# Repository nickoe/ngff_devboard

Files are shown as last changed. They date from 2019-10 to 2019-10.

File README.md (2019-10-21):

View this project on [CADLAB.io](https://cadlab.io/project/2228). 

This is a project to make "something" to put in the WWAN slot of my
laptop. This means M.2 NGFF with key B. Lets try to use USB as a
minimum. Maybe som STM32 chip as a start. Maybe it can be connected to
other things. This in turn means a maximum component area of 30mm x
42mm. Meaning TYPE 3042-xx-B. But I gues we could also go with TYPE
2242-xx-B-M, but this is smaller, but should fit a normal WWAN socket
location as well.

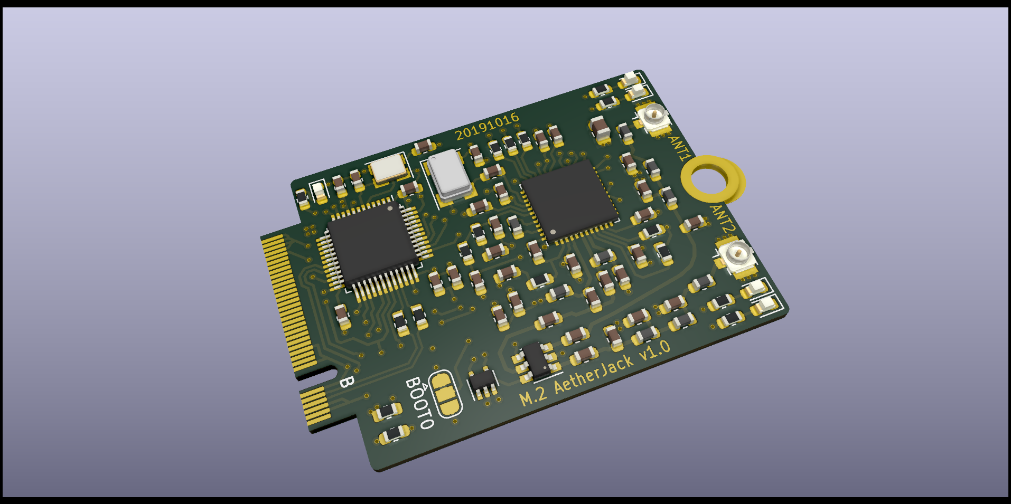
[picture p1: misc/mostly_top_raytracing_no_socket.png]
AetherJack


Or A + E?  Can we do A + B + E?

Even though there are USB in all of above the USB data lines are NOT
in the same pin location :( ... meaning that we go with the B key for
now as this seems to be the most common keying for WWAN modules for
laptops.

Mechanical constraints:
 - Type 3042-S3-B interface
   - 30x42mm
   - Component maximum height on top layer is 1.5mm
   - B keying
   - Board thickness is 0.8 mm.
   - No components on bottom side

   --- or should it be 2242-S3-B? 22mm instead of 30mm wide?
   - Refer to Table 30 for pinout
      Socket 2 Key B SSIC-based WWAN Adapter Pinouts

SIM card connections could be used for SWD programming
Make PCB ready for both STM32F407 and STM32F103

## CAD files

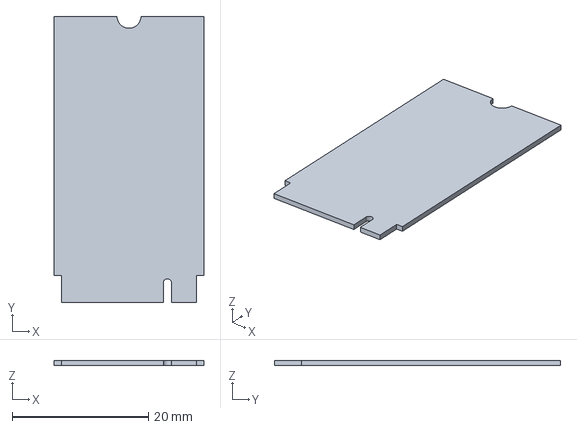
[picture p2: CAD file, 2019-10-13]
M.2 Type 2242-XX-B/M.2 Type 2242-XX-B.step
22.0 x 42.0 x 0.8 mm

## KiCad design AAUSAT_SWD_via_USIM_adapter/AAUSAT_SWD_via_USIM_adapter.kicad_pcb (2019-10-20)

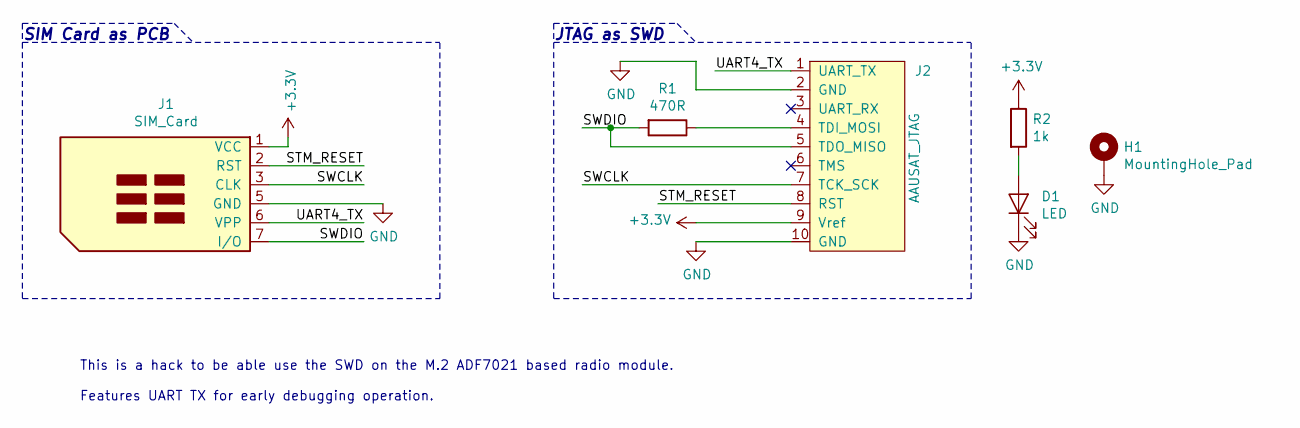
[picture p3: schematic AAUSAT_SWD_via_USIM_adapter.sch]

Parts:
D1: LED; LED_0603_1608Metric
H1: MountingHole_Pad; MountingHole_3.2mm_M3_Pad
J1: SIM_Card; UICC_2FF_mini_SIM_6_pads
J2: AAUSAT_JTAG; S10B-ZR-SM4A-TF(LF)(SN); digikey# 455-1700-1-ND;455-1197-ND;10:455-1130-1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
R1: 470R; R_0603_1608Metric
R2: 1k; R_0603_1608Metric

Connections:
+3V3: J1.1 (VCC), J2.9 (Vref), R2.1
/STM_RESET: J1.2 (RST), J2.8 (RST)
/SWCLK: J1.3 (CLK), J2.7 (TCK_SCK)
/SWDIO: J1.7 (I/O), J2.5 (TDO_MISO), R1.2
/UART4_TX: J1.6 (VPP), J2.1 (UART_TX)
GND: D1.1 (K), H1.1, J1.5 (GND), J2.2 (GND), J2.10 (GND)
unnamed: D1.2 (A), R2.2
unnamed: J2.4 (TDI_MOSI), R1.1

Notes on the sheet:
JTAG as SWD
SIM Card as PCB
This is a hack to be able use the SWD on the M.2 ADF7021 based radio module. Features UART TX for early debugging operation.

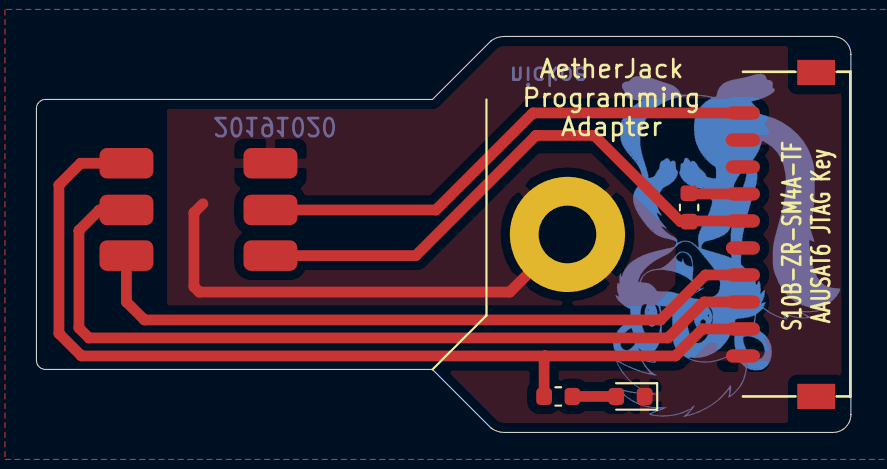
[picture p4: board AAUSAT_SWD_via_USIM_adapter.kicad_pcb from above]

Board: 2 copper layers, 45.2 x 22.0 mm, 6 parts (0 on the bottom side), 8 nets.

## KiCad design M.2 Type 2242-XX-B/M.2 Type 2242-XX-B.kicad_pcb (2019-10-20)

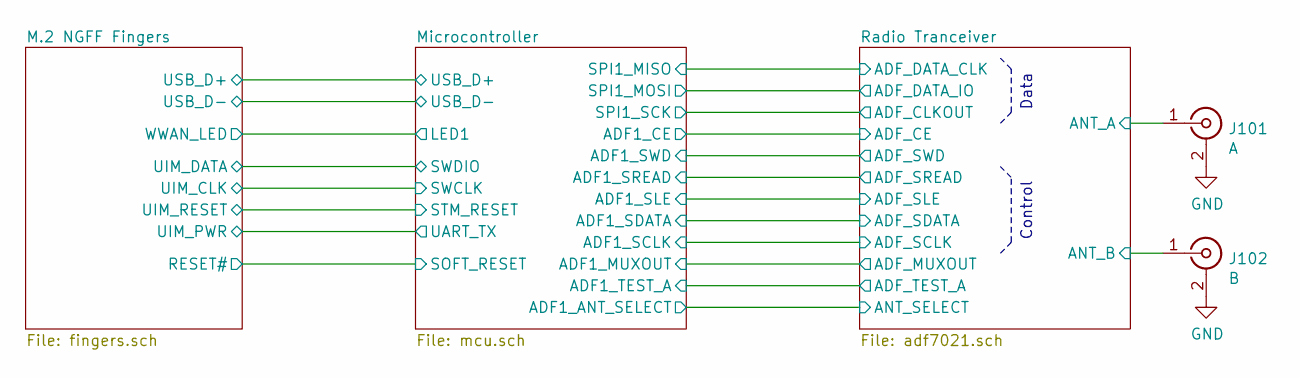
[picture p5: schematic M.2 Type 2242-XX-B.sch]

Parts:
J101: A; U.FL_Hirose_U.FL-R-SMT-1_Vertical
J102: B; U.FL_Hirose_U.FL-R-SMT-1_Vertical

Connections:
/Radio Tranceiver/ANT_A: J101.1 (In); also elsewhere on the board
/Radio Tranceiver/ANT_B: J102.1 (In); also elsewhere on the board
GND: J101.2 (Ext), J102.2 (Ext); also elsewhere on the board

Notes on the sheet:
Control
Data

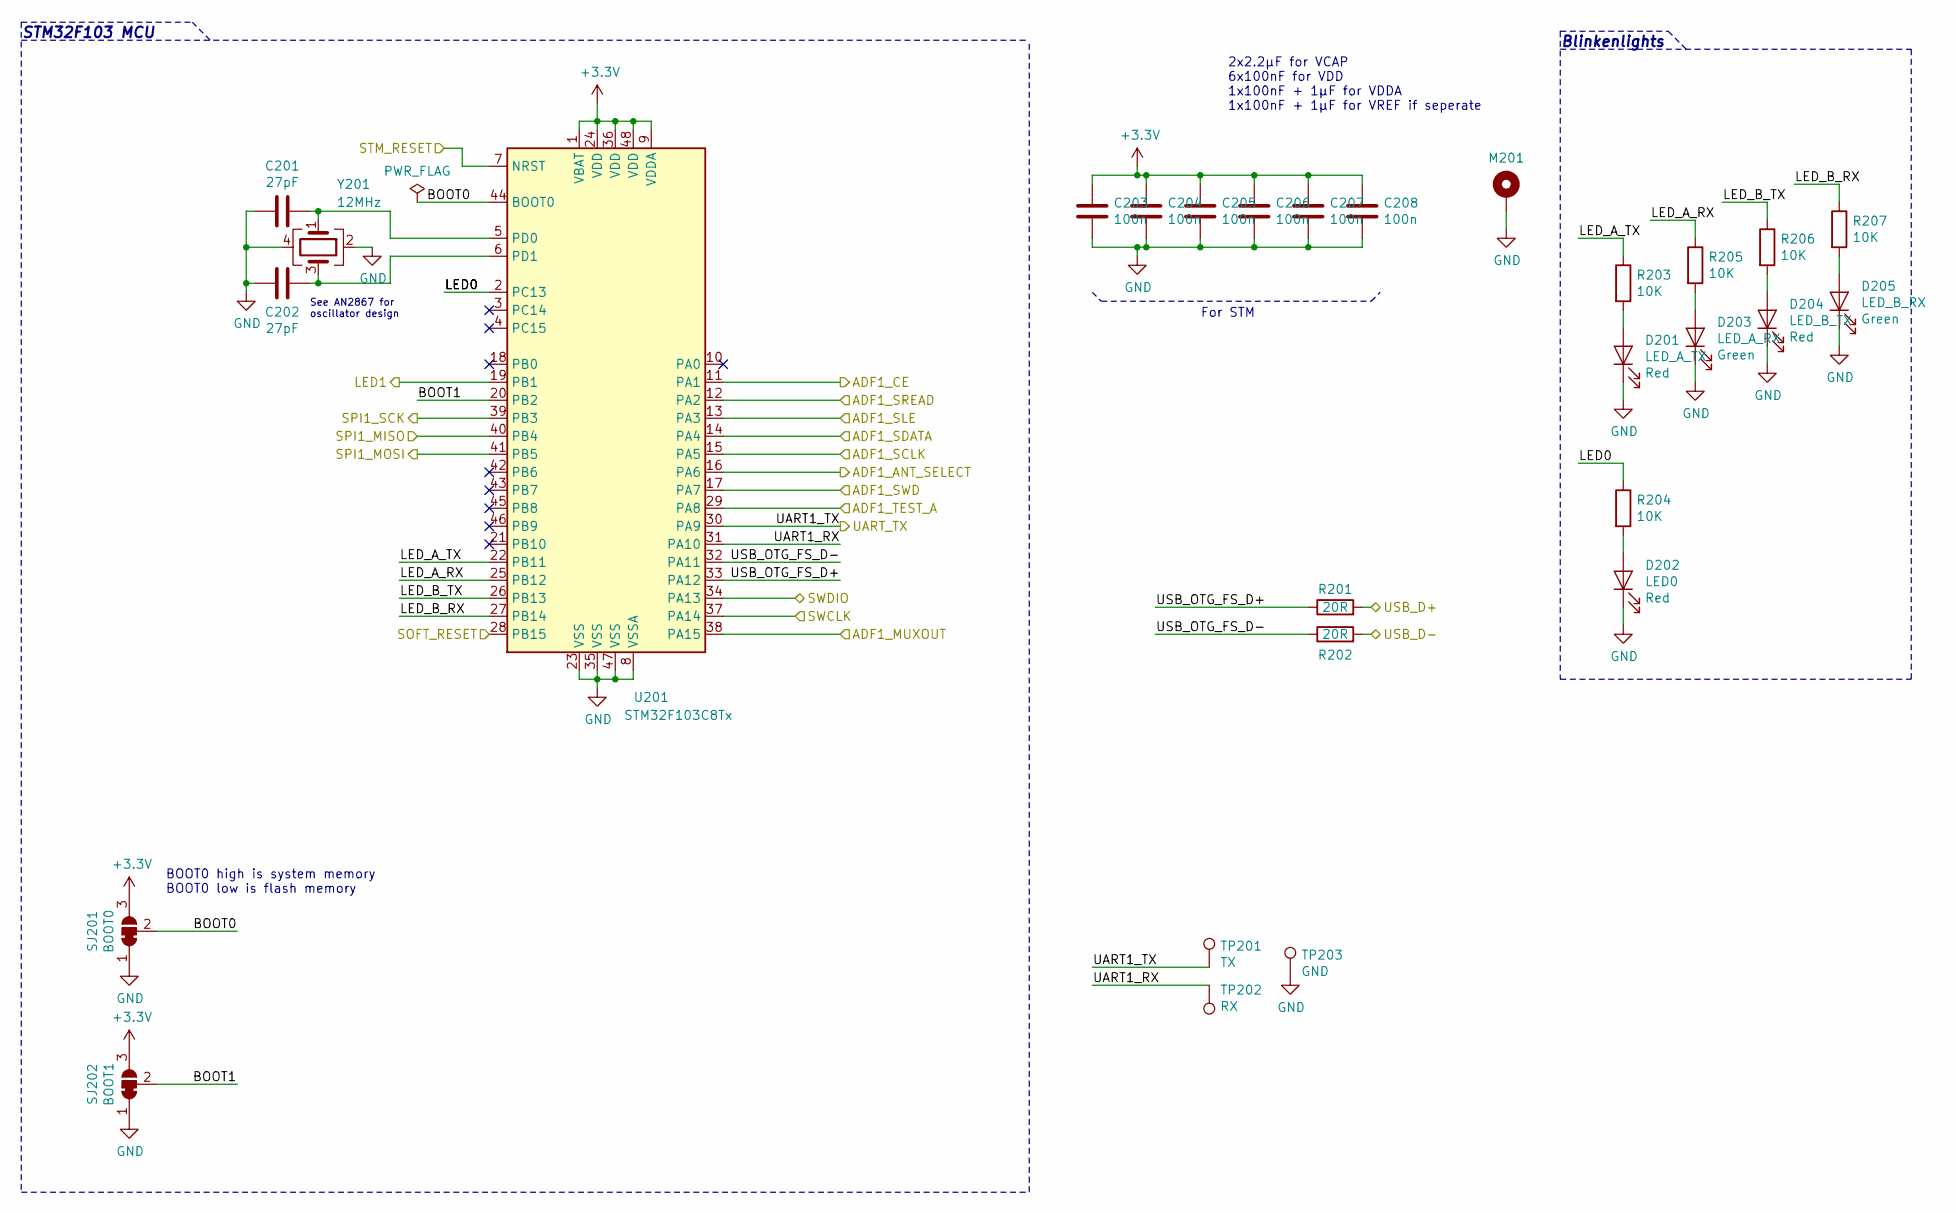
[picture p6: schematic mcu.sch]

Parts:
C201, C202: 27pF; C_0603_1608Metric
C203, C204, C205, C206, C207, C208: 100n; C_0603_1608Metric
D201: LED_A_TX; LED_0603_1608Metric
D202: LED0; LED_0603_1608Metric
D203: LED_A_RX; LED_0603_1608Metric
D204: LED_B_TX; LED_0603_1608Metric
D205: LED_B_RX; LED_0603_1608Metric
M201: MountingHole_Pad; M.2_Standoff_Card_Pad
R201, R202: 20R; R_0603_1608Metric
R203, R204, R205, R206, R207: 10K; R_0603_1608Metric
SJ201: BOOT0; SolderJumper-3_P1.3mm_Bridged12_RoundedPad1.0x1.5mm
SJ202: BOOT1; SolderJumper-3_P1.3mm_Bridged12_RoundedPad1.0x1.5mm
TP201: TX; TestPad
TP202: RX; TestPad
TP203: GND; TestPad
U201: STM32F103C8Tx; LQFP-48_7x7mm_P0.5mm
Y201: 12MHz; Crystal_SMD_3225-4Pin_3.2x2.5mm; digikey# 1923-1568-1-ND

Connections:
+3V3: C203.1, C204.1, C205.1, C206.1, C207.1, C208.1, SJ201.3 (B), SJ202.3 (B), U201.1 (VBAT), U201.9 (VDDA), U201.24 (VDD), U201.36 (VDD), U201.48 (VDD); also elsewhere on the board
/M.2 NGFF Fingers/RESET#: U201.28 (PB15); also elsewhere on the board
/M.2 NGFF Fingers/USB_D+: R201.2; also elsewhere on the board
/M.2 NGFF Fingers/USB_D-: R202.2; also elsewhere on the board
/Microcontroller/ADF1_ANT_SELECT: U201.16 (PA6); also elsewhere on the board
/Microcontroller/ADF1_CE: U201.11 (PA1); also elsewhere on the board
/Microcontroller/ADF1_MUXOUT: U201.38 (PA15); also elsewhere on the board
/Microcontroller/ADF1_SCLK: U201.15 (PA5); also elsewhere on the board
/Microcontroller/ADF1_SDATA: U201.14 (PA4); also elsewhere on the board
/Microcontroller/ADF1_SLE: U201.13 (PA3); also elsewhere on the board
/Microcontroller/ADF1_SREAD: U201.12 (PA2); also elsewhere on the board
/Microcontroller/ADF1_SWD: U201.17 (PA7); also elsewhere on the board
/Microcontroller/ADF1_TEST_A: U201.29 (PA8); also elsewhere on the board
/Microcontroller/BOOT0: SJ201.2 (C), U201.44 (BOOT0)
/Microcontroller/BOOT1: SJ202.2 (C), U201.20 (PB2)
/Microcontroller/LED0: R204.1, U201.2 (PC13)
/Microcontroller/LED1: U201.19 (PB1); also elsewhere on the board
/Microcontroller/LED_A_RX: R205.1, U201.25 (PB12)
/Microcontroller/LED_A_TX: R203.1, U201.22 (PB11)
/Microcontroller/LED_B_RX: R207.1, U201.27 (PB14)
/Microcontroller/LED_B_TX: R206.1, U201.26 (PB13)
/Microcontroller/STM_RESET: U201.7 (NRST); also elsewhere on the board
/Microcontroller/SWCLK: U201.37 (PA14); also elsewhere on the board
/Microcontroller/SWDIO: U201.34 (PA13); also elsewhere on the board
/Microcontroller/UART1_RX: TP202.1, U201.31 (PA10)
/Microcontroller/UART_TX: TP201.1, U201.30 (PA9); also elsewhere on the board
/Microcontroller/USB_OTG_FS_D+: R201.1, U201.33 (PA12)
/Microcontroller/USB_OTG_FS_D-: R202.1, U201.32 (PA11)
/Radio Tranceiver/ADF_CLKOUT: U201.39 (PB3); also elsewhere on the board
/Radio Tranceiver/ADF_DATA_CLK: U201.40 (PB4); also elsewhere on the board
/Radio Tranceiver/ADF_DATA_IO: U201.41 (PB5); also elsewhere on the board
GND: C201.2, C202.2, C203.2, C204.2, C205.2, C206.2, C207.2, C208.2, D201.1 (K), D202.1 (K), D203.1 (K), D204.1 (K), D205.1 (K), M201.1, SJ201.1 (A), SJ202.1 (A), TP203.1, U201.8 (VSSA), U201.23 (VSS), U201.35 (VSS), U201.47 (VSS), Y201.2, Y201.4; also elsewhere on the board
unnamed: C201.1, U201.5 (PD0), Y201.1
unnamed: C202.1, U201.6 (PD1), Y201.3
unnamed: D201.2 (A), R203.2
unnamed: D202.2 (A), R204.2
unnamed: D203.2 (A), R205.2
unnamed: D204.2 (A), R206.2
unnamed: D205.2 (A), R207.2

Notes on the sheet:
See AN2867 for oscillator design
STM32F103 MCU
Blinkenlights
2x2.2µF for VCAP 6x100nF for VDD 1x100nF + 1µF for VDDA 1x100nF + 1µF for VREF if seperate
For STM
BOOT0 high is system memory BOOT0 low is flash memory

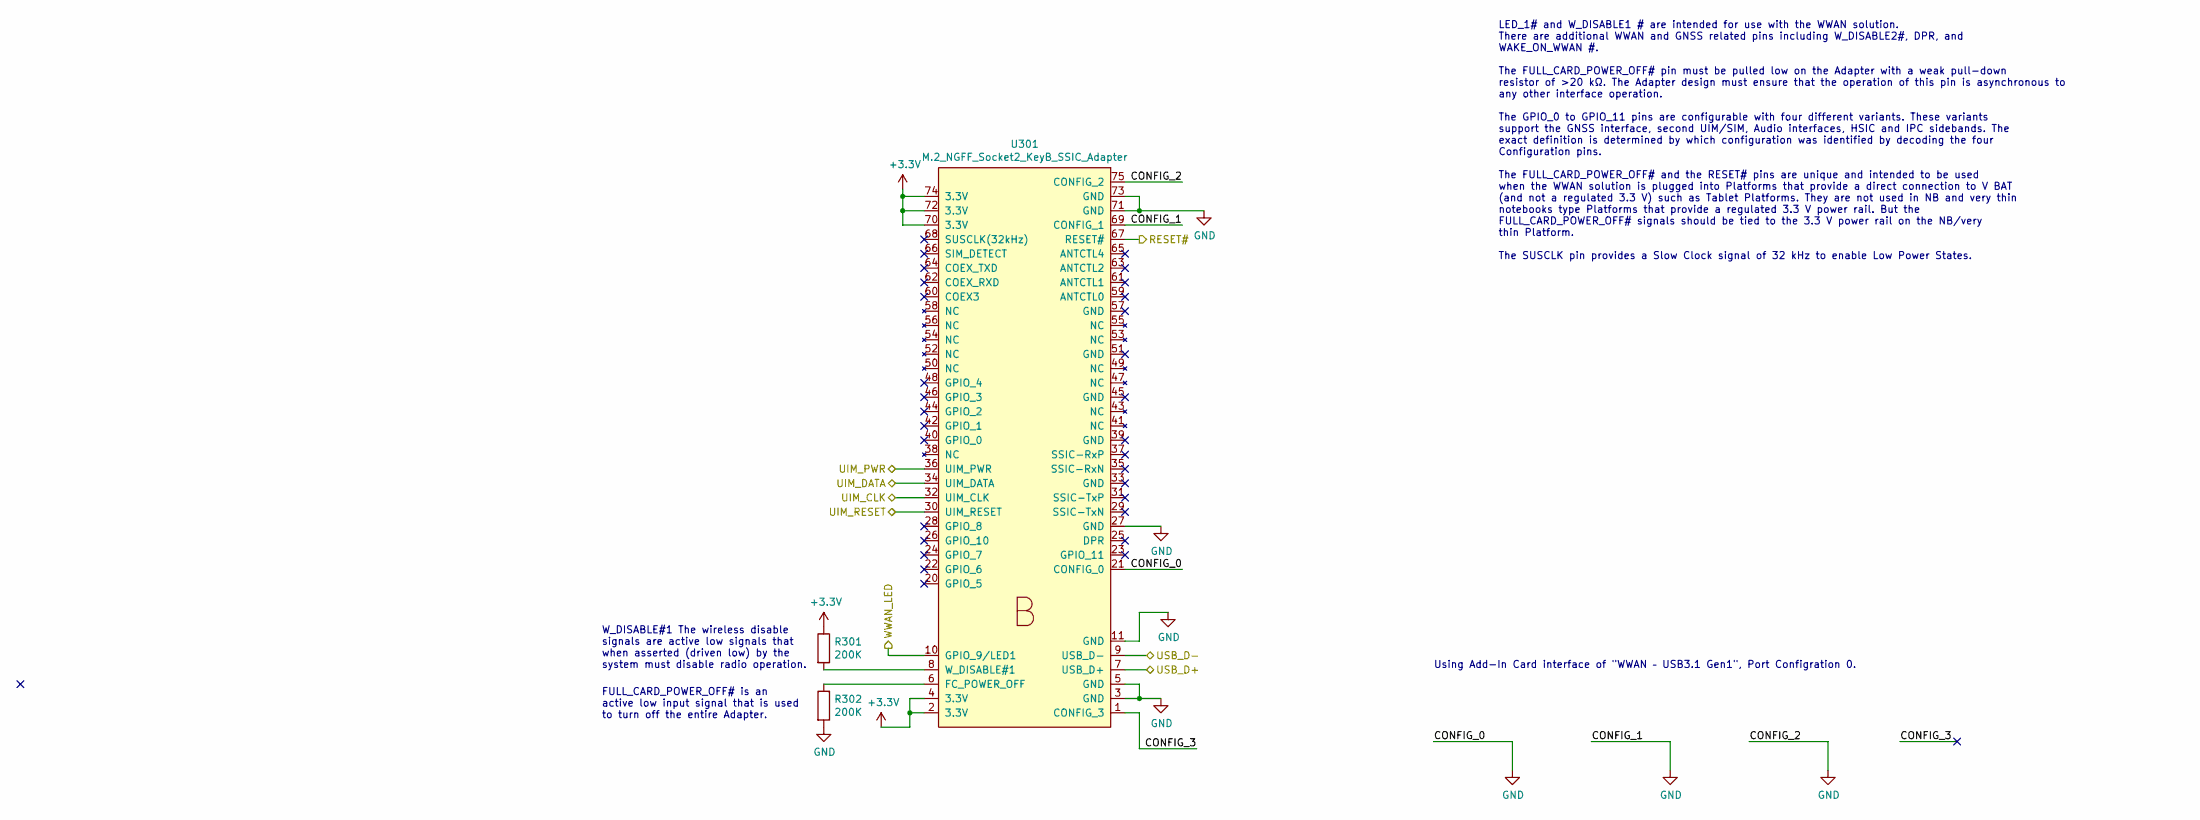
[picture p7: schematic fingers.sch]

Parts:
R301, R302: 200K; R_0603_1608Metric
U301: M.2_NGFF_Socket2_KeyB_SSIC_Adapter; M.2_Key_B_Fingers

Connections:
+3V3: R301.1, U301.2 (3.3V), U301.4 (3.3V), U301.70 (3.3V), U301.72 (3.3V), U301.74 (3.3V); also elsewhere on the board
/M.2 NGFF Fingers/CONFIG_3: U301.1 (CONFIG_3)
/M.2 NGFF Fingers/RESET#: U301.67 (RESET#); also elsewhere on the board
/M.2 NGFF Fingers/USB_D+: U301.7 (USB_D+); also elsewhere on the board
/M.2 NGFF Fingers/USB_D-: U301.9 (USB_D-); also elsewhere on the board
/Microcontroller/LED1: U301.10 (GPIO_9/LED1); also elsewhere on the board
/Microcontroller/STM_RESET: U301.30 (UIM_RESET); also elsewhere on the board
/Microcontroller/SWCLK: U301.32 (UIM_CLK); also elsewhere on the board
/Microcontroller/SWDIO: U301.34 (UIM_DATA); also elsewhere on the board
/Microcontroller/UART_TX: U301.36 (UIM_PWR); also elsewhere on the board
GND: R302.2, U301.3 (GND), U301.5 (GND), U301.11 (GND), U301.21 (CONFIG_0), U301.27 (GND), U301.69 (CONFIG_1), U301.71 (GND), U301.73 (GND), U301.75 (CONFIG_2); also elsewhere on the board
unnamed: R301.2, U301.8 (W_DISABLE#1)
unnamed: R302.1, U301.6 (FC_POWER_OFF)

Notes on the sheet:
LED_1# and W_DISABLE1 # are intended for use with the WWAN solution. There are additional WWAN and GNSS related pins including W_DISABLE2#, DPR, and WAKE_ON_WWAN #. The FULL_CARD_POWER_OFF# pin must be pulled low on the Adapter with a weak pull-down resistor of >20 kΩ. The Adapter design must ensur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
FULL_CARD_POWER_OFF# is an active low input signal that is used to turn off the entire Adapter.
W_DISABLE#1 The wireless disable signals are active low signals that when asserted (driven low) by the system must disable radio operation.
Using Add-In Card interface of "WWAN – USB3.1 Gen1", Port Configration 0.

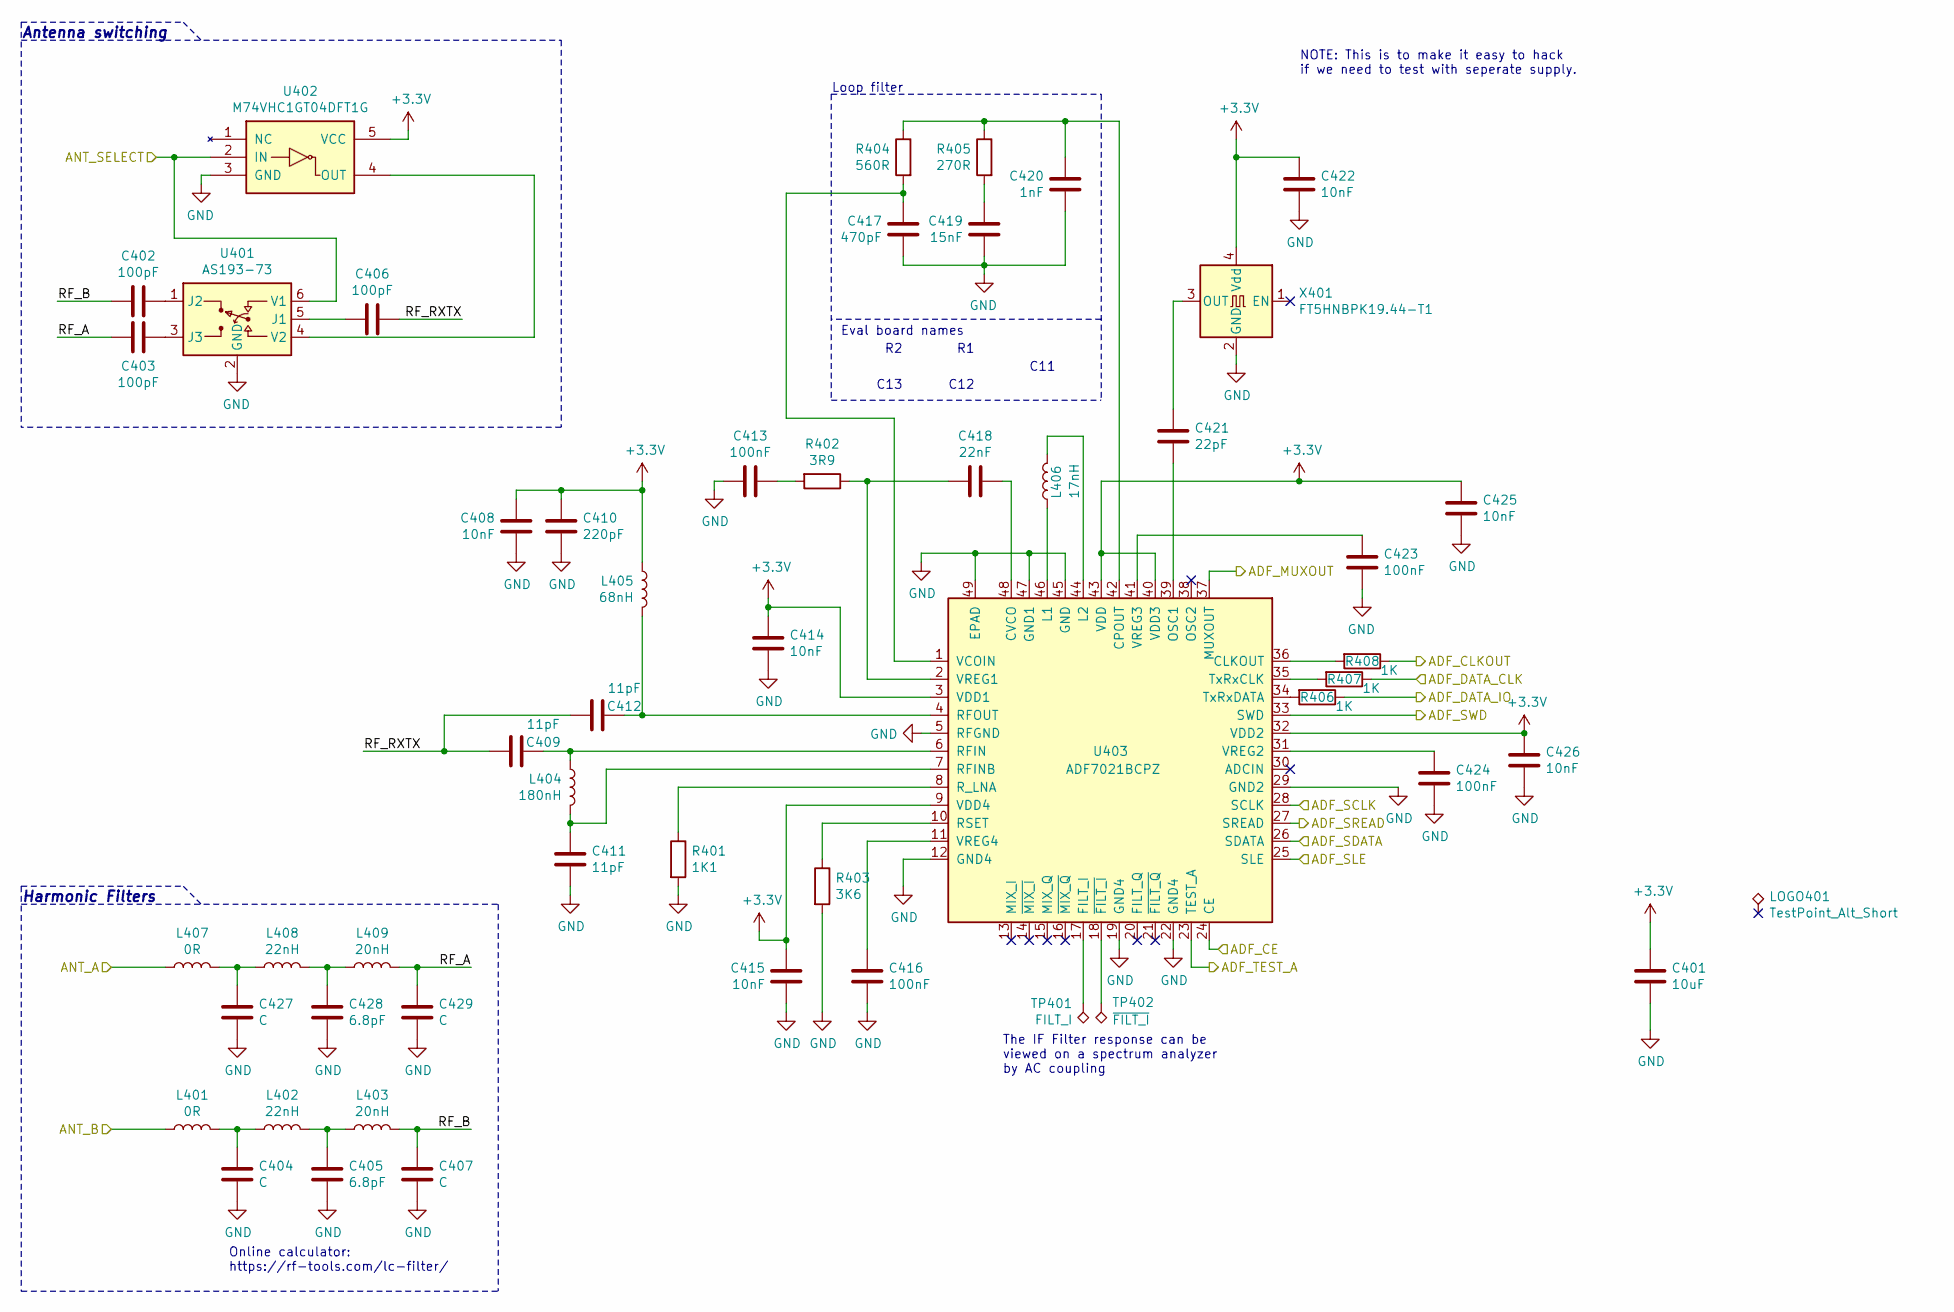
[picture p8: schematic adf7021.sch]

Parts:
C401: 10uF; C_0805_2012Metric
C402, C403, C406: 100pF; C_0603_1608Metric
C404, C407, C427, C429: C; C_0603_1608Metric
C405, C428: 6.8pF; C_0603_1608Metric
C408, C414, C415, C422, C425, C426: 10nF; C_0603_1608Metric
C409, C411, C412: 11pF; C_0603_1608Metric
C410: 220pF; C_0603_1608Metric
C413, C416, C423, C424: 100nF; C_0603_1608Metric
C417: 470pF; C_0603_1608Metric
C418: 22nF; C_0603_1608Metric
C419: 15nF; C_0603_1608Metric
C420: 1nF; C_0603_1608Metric
C421: 22pF; C_0603_1608Metric
L401, L407: 0R; L_0603_1608Metric
L402, L408: 22nH; L_0603_1608Metric
L403, L409: 20nH; L_0603_1608Metric
L404: 180nH; L_0603_1608Metric
L405: 68nH; L_0603_1608Metric
L406: 17nH; L_0603_1608Metric
LOGO401: TestPoint_Alt_Short; KiCad-Logo_Back
R401: 1K1; R_0603_1608Metric
R402: 3R9; R_0603_1608Metric
R403: 3K6; R_0603_1608Metric
R404: 560R; R_0603_1608Metric
R405: 270R; R_0603_1608Metric
R406, R407, R408: 1K; R_0603_1608Metric
TP401: FILT_I; TestPad
TP402: ~FILT_I; TestPad
U401: AS193-73; SuperSOT-6
U402: M74VHC1GT04DFT1G; SOT-353_SC-70-5; digikey# M74VHC1GT04DFT1GOSCT-ND
U403: ADF7021BCPZ; LFCSP-48-1EP_7x7mm_P0.5mm_EP4.1x4.1mm_ThermalVias
X401: FT5HNBPK19.44-T1; FOX924; digikey# 631-1072-1-ND

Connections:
+3V3: C401.1, C408.1, C410.1, C414.1, C415.1, C422.1, C425.1, C426.1, L405.1, U402.5 (VCC), U403.3 (VDD1), U403.9 (VDD4), U403.32 (VDD2), U403.40 (VDD3), U403.43 (VDD), X401.4 (Vdd); also elsewhere on the board
/Microcontroller/ADF1_ANT_SELECT: U401.6 (V1), U402.2 (IN); also elsewhere on the board
/Microcontroller/ADF1_CE: U403.24 (CE); also elsewhere on the board
/Microcontroller/ADF1_MUXOUT: U403.37 (MUXOUT); also elsewhere on the board
/Microcontroller/ADF1_SCLK: U403.28 (SCLK); also elsewhere on the board
/Microcontroller/ADF1_SDATA: U403.26 (SDATA); also elsewhere on the board
/Microcontroller/ADF1_SLE: U403.25 (SLE); also elsewhere on the board
/Microcontroller/ADF1_SREAD: U403.27 (SREAD); also elsewhere on the board
/Microcontroller/ADF1_SWD: U403.33 (SWD); also elsewhere on the board
/Microcontroller/ADF1_TEST_A: U403.23 (TEST_A); also elsewhere on the board
/Radio Tranceiver/ADF_CLKOUT: R408.1; also elsewhere on the board
/Radio Tranceiver/ADF_DATA_CLK: R407.1; also elsewhere on the board
/Radio Tranceiver/ADF_DATA_IO: R406.1; also elsewhere on the board
/Radio Tranceiver/ANT_A: L407.1; also elsewhere on the board
/Radio Tranceiver/ANT_B: L401.1; also elsewhere on the board
/Radio Tranceiver/RF_A: C403.2, C429.1, L409.2
/Radio Tranceiver/RF_B: C402.2, C407.1, L403.2
/Radio Tranceiver/RF_RXTX: C406.1, C409.1, C412.1
GND: C401.2, C404.2, C405.2, C407.2, C408.2, C410.2, C411.2, C413.2, C414.2, C415.2, C416.2, C417.2, C419.2, C420.2, C422.2, C423.2, C424.2, C425.2, C426.2, C427.2, C428.2, C429.2, R401.2, R403.2, U401.2 (GND), U402.3 (GND), U403.5 (RFGND), U403.12 (GND4), U403.19 (GND4), U403.22 (GND4), U403.29 (GND2), U403.45 (GND), U403.47 (GND1), U403.49 (EPAD), X401.2 (GND); also elsewhere on the board
unnamed: C402.1, U401.1 (J2)
unnamed: C403.1, U401.3 (J3)
unnamed: C404.1, L401.2, L402.1
unnamed: C405.1, L402.2, L403.1
unnamed: C406.2, U401.5 (J1)
unnamed: C409.2, L404.1, U403.6 (RFIN)
unnamed: C411.1, L404.2, U403.7 (RFINB)
unnamed: C412.2, L405.2, U403.4 (RFOUT)
unnamed: C413.1, R402.2
unnamed: C416.1, U403.11 (VREG4)
unnamed: C417.1, R404.2, U403.1 (VCOIN)
unnamed: C418.1, U403.48 (CVCO)
unnamed: C418.2, R402.1, U403.2 (VREG1)
unnamed: C419.1, R405.2
unnamed: C420.1, R404.1, R405.1, U403.42 (CPOUT)
unnamed: C421.1, X401.3 (OUT)
unnamed: C421.2, U403.39 (OSC1)
unnamed: C423.1, U403.41 (VREG3)
unnamed: C424.1, U403.31 (VREG2)
unnamed: C427.1, L407.2, L408.1
unnamed: C428.1, L408.2, L409.1
unnamed: L406.1, U403.46 (L1)
unnamed: L406.2, U403.44 (L2)
unnamed: R401.1, U403.8 (R_LNA)
unnamed: R403.1, U403.10 (RSET)
unnamed: R406.2, U403.34 (TxRxDATA)
unnamed: R407.2, U403.35 (TxRxCLK)
unnamed: R408.2, U403.36 (CLKOUT)
unnamed: TP401.1, U403.17 (FILT_I)
unnamed: TP402.1, U403.18 (~FILT_I)
unnamed: U401.4 (V2), U402.4 (OUT)

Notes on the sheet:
Antenna switching
NOTE: This is to make it easy to hack if we need to test with seperate supply.
The IF Filter response can be viewed on a spectrum analyzer by AC coupling
Loop filter
Eval board names
C13
C12
C11
Online calculator: https://rf-tools.com/lc-filter/
Harmonic Filters

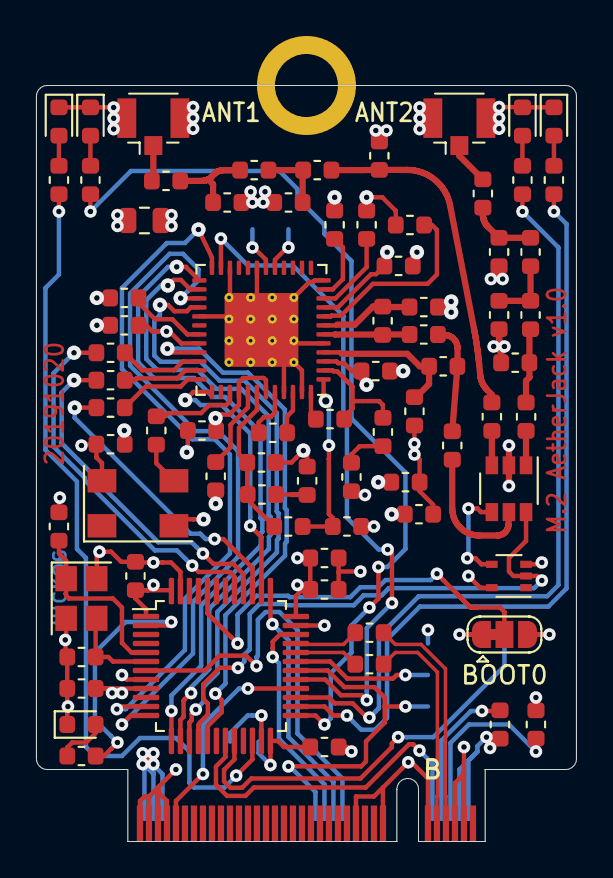
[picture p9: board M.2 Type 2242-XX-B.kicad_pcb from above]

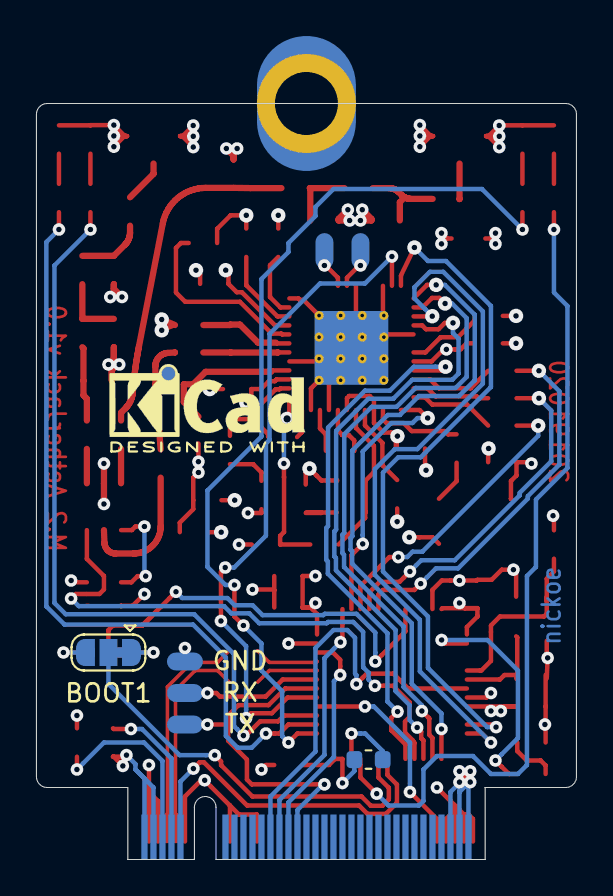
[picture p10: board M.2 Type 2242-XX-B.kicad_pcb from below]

Board: 4 copper layers, 30.0 x 42.0 mm, 86 parts (8 on the bottom side), 77 nets.

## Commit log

2019-10-13 Add gitignore for kicad files
2019-10-13 Add initial schematic for M.2 board
    [M.2 Type 2242-XX-B.kicad_pcb, M.2 Type 2242-XX-B.sch, M.2 Type 2242-XX-B.step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]
2019-10-13 Add SWD via SIM card adapter
    [AAUSAT_SWD_via_USIM_adapter.kicad_pcb, AAUSAT_SWD_via_USIM_adapter.sch]
2019-10-13 Add proper footprint to solder jumpers
    [M.2 Type 2242-XX-B.kicad_pcb, adf7021.sch, fingers.sch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]
2019-10-14 NOP Update
    [adf7021.sch, fingers.sch]
2019-10-14 Initial placement, I think we are going for the STM32F103 instead
    The LQPF-100 is simply too big
    [M.2 Type 2242-XX-B.kicad_pcb, adf7021.sch, fingers.sch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]
2019-10-14 Schematic updated to STM32F103
    [M.2 Type 2242-XX-B.kicad_pcb, M.2 Type 2242-XX-B.sch, adf7021.sch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]
2019-10-14 Almost everything placed
    [M.2 Type 2242-XX-B.kicad_pcb, M.2 Type 2242-XX-B.sch, adf7021.sch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]
2019-10-14 Remove the solder pads for the config pins
    Lets hope it is working as is. The board does not really have a lot of
    real estate left...
    [M.2 Type 2242-XX-B.kicad_pcb, fingers.sch]
2019-10-15 Fix 3D model path for M.2 connector
    [M.2 Type 2242-XX-B.kicad_pcb]
2019-10-15 Board more or less completely routed
    [M.2 Type 2242-XX-B.kicad_pcb, fingers.sch]
2019-10-16 Update clearance rules for M.2 fingers
    [M.2 Type 2242-XX-B.kicad_pcb, M.2 Type 2242-XX-B.sch]
2019-10-16 Add project named, data and antenna numbers
    [M.2 Type 2242-XX-B.kicad_pcb]
2019-10-18 Shorten adapter, it was a bit too long
    [AAUSAT_SWD_via_USIM_adapter.kicad_pcb]
2019-10-19 Add rounded corners
    [M.2 Type 2242-XX-B.kicad_pcb]
2019-10-20 Fix DRC error with ANT1/2 in copper
    Add solder mask removal for RF traces
    [M.2 Type 2242-XX-B.kicad_pcb]
2019-10-20 Add skunk and name of board
    [AAUSAT_SWD_via_USIM_adapter.kicad_pcb]
2019-10-20 Adjust my nickname
    [M.2 Type 2242-XX-B.kicad_pcb]
2019-10-20 Add date on adapter
    [AAUSAT_SWD_via_USIM_adapter.kicad_pcb]
